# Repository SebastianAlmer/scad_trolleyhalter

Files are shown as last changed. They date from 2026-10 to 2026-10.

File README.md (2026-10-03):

# Trolleyhalter für GPS mit Magnet

3D-druckbarer Halter, um ein GPS-Gerät mit Magnet-Rückseite am Rohr eines
(Golf-)Trolleys zu befestigen. Als Haftfläche für den Magneten dient eine
eingeklickte Stahl-Beilagscheibe, befestigt wird der Halter mit Kabelbindern.

| Oben (Scheibenaufnahme) | Unten (Sattel + Ösen) |
|---|---|
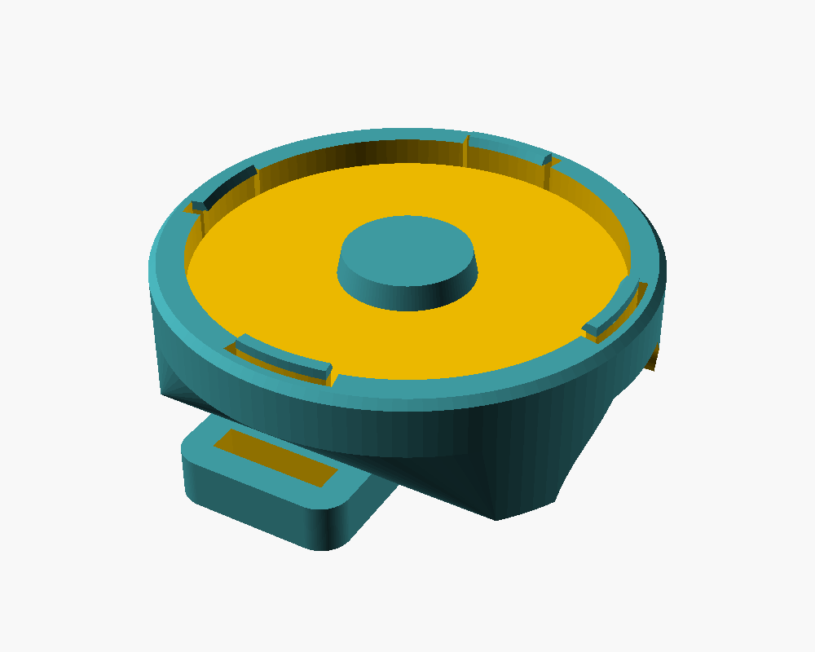
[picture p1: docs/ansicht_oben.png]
Ansicht oben
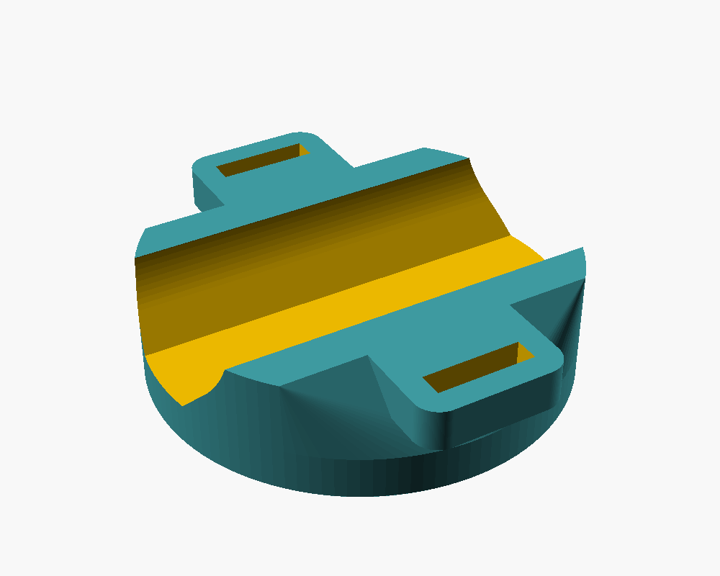
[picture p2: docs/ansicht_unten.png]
Ansicht unten
|  |  |

## Aufbau

- **Scheibenaufnahme:** Tasche für die Beilagscheibe mit Zentrierzapfen und
  vier federnden Schnapplaschen. Die Scheibe wird von oben eingedrückt und
  rastet ein.
- **Sattel:** Angepasst an den Rohrdurchmesser, damit der Halter nicht verdreht.
- **Ösen:** Je eine breite Öse links und rechts vom Rohr. Der Kabelbinder läuft
  durch beide Ösen und um das Rohr.

## Benötigte Teile

- Stahl-Beilagscheibe 44 × 14,5 × 3 mm (Karosseriescheibe, z. B. DIN 9021 M14)
- 1 Kabelbinder, bis 12 mm breit (alternativ 20 mm Klettband, siehe unten)

## Dateien

| Datei | Inhalt |
|---|---|
| [`OpenSCAD/trolleyhalter.scad`](OpenSCAD/trolleyhalter.scad) | Parametrisches Modell |
| [`OpenSCAD/trolleyhalter.stl`](OpenSCAD/trolleyhalter.stl) | Fertig exportiert für die Standardmaße |
| [`input/`](input/) | Referenzfotos (Beilagscheibe, alter Halter) |
| [`docs/`](docs/) | Vorschaubilder |

## Anpassen

Alle Maße stehen oben in der `.scad`-Datei und lassen sich auch im
OpenSCAD-Customizer ändern. Die wichtigsten:

| Parameter | Standard | Bedeutung |
|---|---|---|
| `tube_d` | 25 | Rohrdurchmesser des Trolleys, **vor dem Druck nachmessen** |
| `pad_t` | 0 | Dicke einer Gummi-Zwischenlage (z. B. 1) |
| `washer_d` / `washer_hole` / `washer_t` | 44 / 14,5 / 3 | Maße der Beilagscheibe |
| `fit_clear` | 0,3 | Spiel der Scheibe in der Tasche |
| `lip_in` / `clip_t` | 0,6 / 1,2 | Rastnase / Laschendicke: kleiner = leichter einklicken |
| `strap_w` / `strap_t` | 12 / 3 | Ösenloch; für 20 mm Klettband: 22 / 3,5 |
| `eyelet_count` | 1 | Ösen pro Seite (1 = mittig, 2 = vorne + hinten) |

Nach Änderungen in OpenSCAD mit **F6** rendern und als STL exportieren, oder per
Kommandozeile:

```sh
openscad -o OpenSCAD/trolleyhalter.stl OpenSCAD/trolleyhalter.scad
```

## Drucken

- Ausrichtung wie in der STL: Sattel auf dem Druckbett, Scheibenaufnahme oben
- **Keine Stützstrukturen** nötig
- Material: PETG oder ASA (PLA wird in der Sonne bzw. im Auto weich)
- 0,2 mm Schichthöhe, 3 Wände, 30–40 % Füllung

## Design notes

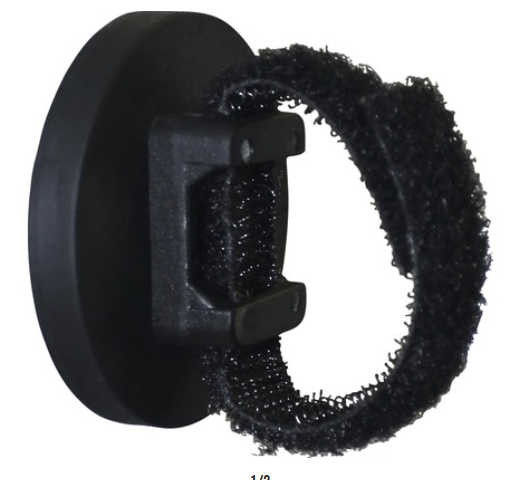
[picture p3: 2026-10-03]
input/alter_halter.png

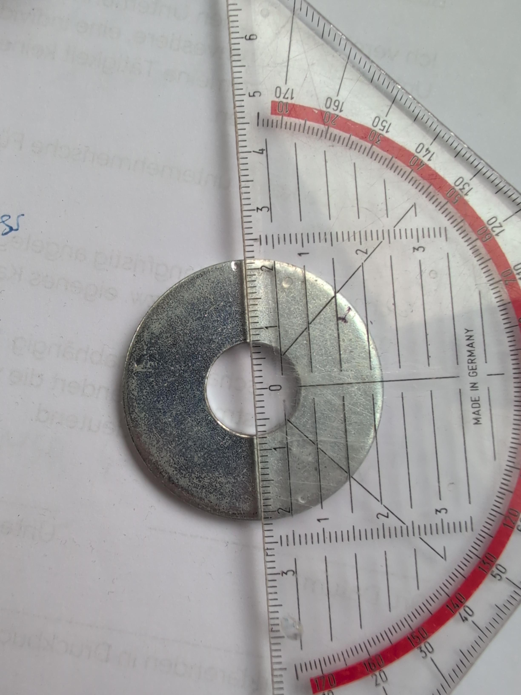
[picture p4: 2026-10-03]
input/beilagscheibe_mass.jpeg

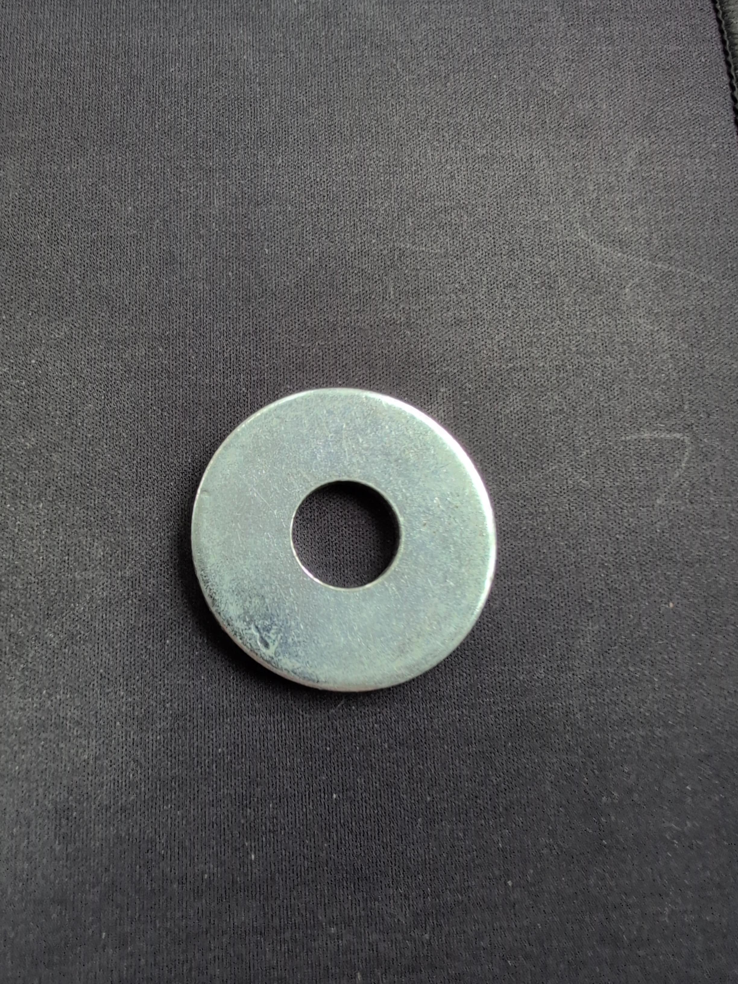
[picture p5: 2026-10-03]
input/beilagscheibe.jpeg

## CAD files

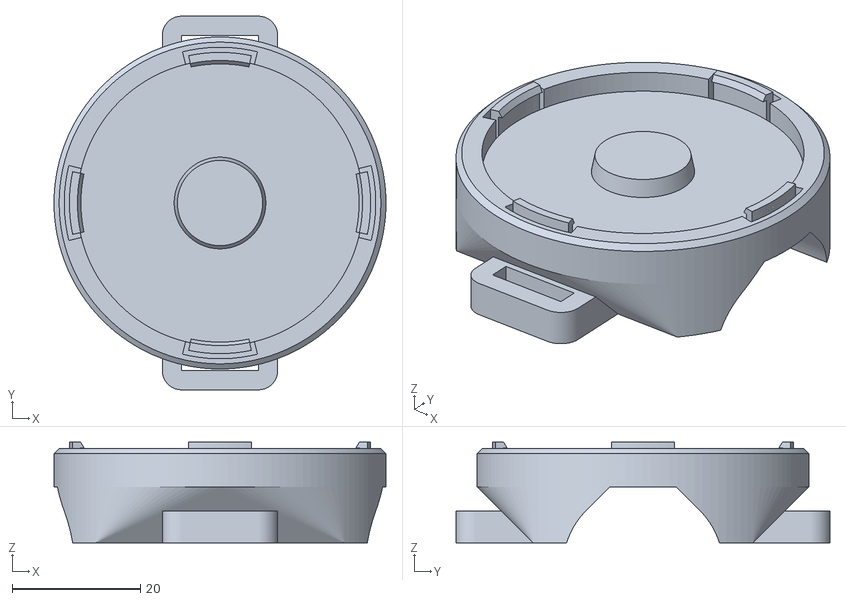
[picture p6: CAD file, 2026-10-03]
OpenSCAD/trolleyhalter.stl
51.8 x 58.3 x 15.8

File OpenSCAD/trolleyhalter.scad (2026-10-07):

// Trolleyhalter fuer GPS mit Magnet
// Eine Stahl-Beilagscheibe wird oben eingeklickt (Magnet-Aufnahme),
// unten sitzt ein Sattel fuer das Trolley-Rohr. Befestigung mit
// Kabelbindern durch Oesen auf beiden Seiten, um das Rohr herum.
//
// Druck: so wie exportiert (Sattel auf dem Druckbett, Scheibenseite oben),
// keine Stuetzen noetig. PETG oder ASA empfohlen (Flex der Laschen, UV).

/* [Beilagscheibe] */
washer_d    = 44;    // Aussendurchmesser (gemessen ca. 44 mm)
washer_hole = 14.5;  // Lochdurchmesser (gemessen ca. 14-15 mm)
washer_t    = 3;     // Dicke
fit_clear   = 0.3;   // Spiel am Aussendurchmesser

/* [Schnapplaschen] */
clip_count  = 4;     // Anzahl Laschen
clip_angle  = 24;    // Breite einer Lasche in Grad
clip_t      = 1.2;   // Wandstaerke der Lasche (duenner = weicher)
clip_gap    = 0.8;   // Freischnitt hinter / neben der Lasche
lip_in      = 0.6;   // Ueberstand der Rastnase ueber den Scheibenrand
lip_h       = 0.9;   // Hoehe der Rastnase ueber der Scheibe
lip_clear   = 0.1;   // Luft zwischen Scheibe und Rastnase

/* [Rohr] */
tube_d      = 40;    // Rohrdurchmesser des Trolleys
pad_t       = 0;     // Dicke einer optionalen Gummi-Zwischenlage (z.B. 1)
saddle_frac = 0.35;  // Wie tief der Sattel das Rohr umgreift (Anteil vom Durchmesser)

/* [Kabelbinder-Oesen] */
eyelet_count = 1;    // Oesen pro Seite (1 = mittig, 2 = vorne + hinten)
strap_w      = 12;   // Lochlaenge (breite Kabelbinder bis ~12 mm, auch doppelt)
strap_t      = 3;    // Lochbreite (Kabelbinder-Dicke + Luft)
eyelet_wall  = 3;    // Materialstaerke um das Loch
eyelet_h     = 5;    // Dicke der Oese
eyelet_pitch = 26;   // Abstand der Oesen entlang dem Rohr (bei 2 Oesen)

/* [Gehaeuse] */
outer_wall  = 1.6;   // Aussenwand hinter den Laschen
floor_t     = 3;     // Boden unter der Scheibe (ueber dem Rohrscheitel)
chamfer     = 0.8;

$fn = 120;

// ---- abgeleitete Masse ----
pocket_r = washer_d / 2 + fit_clear;
wall     = clip_t + clip_gap + outer_wall;
body_r   = pocket_r + wall;
body_d   = 2 * body_r;
tube_r   = tube_d / 2 + pad_t;
saddle_h = tube_d * saddle_frac;

pocket_z = floor_t;                      // Taschenboden
body_h   = pocket_z + washer_t;          // Scheibe liegt buendig mit der Oberkante
relief_z = 0.6;                          // Unterkante der Laschen-Freischnitte

// Breite des Sattelblocks so, dass die Unterseite des Pucks
// mit max. 45 Grad abfaellt (druckbar ohne Stuetzen)
chord    = 2 * sqrt(tube_r * tube_r - pow(tube_r - saddle_h, 2));
saddle_w = max(chord + 6, body_d - 2 * saddle_h);

module puck() {
    cylinder(r = body_r, h = body_h - chamfer);
    translate([0, 0, body_h - chamfer])
        cylinder(r1 = body_r, r2 = body_r - chamfer, h = chamfer);
}

module saddle_block() {
    intersection() {
        translate([-body_r, -saddle_w / 2, -saddle_h])
            cube([body_d, saddle_w, saddle_h + 0.01]);
        translate([0, 0, -saddle_h]) cylinder(r = body_r, h = saddle_h + 0.01);
    }
}

module body() {
    hull() {
        puck();
        saddle_block();
    }
}

// Rohr entlang X, Scheitel bei z = 0. Oben abgeflachte Tropfenform,
// damit die Wölbung beim Druck nur eine kurze Bruecke braucht.
module tube_cut() {
    rotate([0, 90, 0])
        linear_extrude(height = 2 * body_d, center = true)
            intersection() {
                hull() {
                    translate([tube_r, 0]) circle(r = tube_r);
                    translate([tube_r - tube_r * sqrt(2), 0])
                        square(0.01, center = true);
                }
                // Abflachung am Scheitel (z = 0 entspricht x = 0 nach rotate)
                translate([0, -tube_d]) square([4 * tube_d, 2 * tube_d]);
            }
}

// Oesen links und rechts vom Rohr, unten am Sattel. Der Kabelbinder
// laeuft senkrecht durch das Loch und um das Rohr herum.
eyelet_xs  = eyelet_count == 1 ? [0] : [-eyelet_pitch / 2, eyelet_pitch / 2];
eyelet_len = strap_w + 2 * eyelet_wall;            // entlang dem Rohr
hole_y     = saddle_w / 2 + eyelet_h + 1;          // Innenkante Loch, frei von der Schraege
eyelet_y   = hole_y + strap_t + eyelet_wall;       // Aussenkante Oese

module eyelets() {
    for (sy = [-1, 1], x = eyelet_xs)
        mirror([0, sy < 0 ? 1 : 0, 0])
            translate([x, 0, -saddle_h])
                hull() {
                    translate([-eyelet_len / 2, 0, 0])
                        cube([eyelet_len, 0.01, eyelet_h]);
                    for (dx = [-1, 1])
                        translate([dx * (eyelet_len / 2 - eyelet_wall), eyelet_y - eyelet_wall, 0])
                            cylinder(r = eyelet_wall, h = eyelet_h);
                }
}

module eyelet_holes() {
    for (sy = [-1, 1], x = eyelet_xs)
        mirror([0, sy < 0 ? 1 : 0, 0])
            translate([x - strap_w / 2, hole_y, -saddle_h - 1])
                cube([strap_w, strap_t, eyelet_h + 2]);
}

module ring_sector(r_in, r_out, z0, h, a0, a) {
    translate([0, 0, z0])
        rotate([0, 0, a0])
            rotate_extrude(angle = a)
                translate([r_in, 0]) square([r_out - r_in, h]);
}

module washer_pocket() {
    translate([0, 0, pocket_z]) {
        cylinder(r = pocket_r, h = body_h);
    }
}

// Freischnitte, die aus der Taschenwand federnde Laschen machen
module clip_reliefs() {
    gap_a  = clip_gap / (pocket_r + clip_t) * 180 / PI;   // Seitenschlitz in Grad
    for (i = [0 : clip_count - 1]) {
        a = i * 360 / clip_count;
        // hinter der Lasche
        ring_sector(pocket_r + clip_t, pocket_r + clip_t + clip_gap,
                    relief_z, body_h, a - clip_angle / 2 - gap_a, clip_angle + 2 * gap_a);
        // seitlich
        for (s = [-1, 1])
            ring_sector(pocket_r - 0.01, pocket_r + clip_t + 0.01,
                        relief_z, body_h,
                        a + s * clip_angle / 2 - (s < 0 ? gap_a : 0), gap_a);
    }
}

// Rastnasen oben auf den Laschen: innen 45-Grad-Einfuehrschraege,
// unten flache Rastkante (druckt als 0.6 mm Ueberhang, kein Problem)
module clip_lips() {
    for (i = [0 : clip_count - 1]) {
        a = i * 360 / clip_count;
        translate([0, 0, body_h + lip_clear])
            rotate([0, 0, a - clip_angle / 2])
                rotate_extrude(angle = clip_angle)
                    polygon([
                        [pocket_r - lip_in, 0],
                        [pocket_r + clip_t, 0],
                        [pocket_r + clip_t, lip_h],
                        [pocket_r - lip_in + lip_h * 0.6, lip_h],
                    ]);
        // Steg zwischen Lasche und Nase (fuellt den Spalt lip_clear)
        ring_sector(pocket_r, pocket_r + clip_t, body_h - 0.01, lip_clear + 0.02,
                    a - clip_angle / 2, clip_angle);
    }
}

// Zentrierzapfen im Scheibenloch
module center_peg() {
    translate([0, 0, pocket_z - 0.01])
        cylinder(d1 = washer_hole - 0.2, d2 = washer_hole - 1.2, h = washer_t - 0.4);
}

module holder() {
    difference() {
        union() {
            body();
            eyelets();
        }
        tube_cut();
        eyelet_holes();
        washer_pocket();
        clip_reliefs();
    }
    clip_lips();
    center_peg();
}

module washer_preview() {
    %translate([0, 0, pocket_z])
        difference() {
            cylinder(d = washer_d, h = washer_t);
            translate([0, 0, -1]) cylinder(d = washer_hole, h = washer_t + 2);
        }
}

// Druckausrichtung: Sattel unten auf dem Bett
translate([0, 0, saddle_h]) {
    holder();
    washer_preview();
}
